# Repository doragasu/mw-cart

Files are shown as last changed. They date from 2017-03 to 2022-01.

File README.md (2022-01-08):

# WARNING: THIS PROJECT HAS MOVED

You can find the most recent version at the [mw-cart GitLab project page](https://gitlab.com/doragasu/mw-cart). This repository will be kept as is, and will not be updated anymore.

# mw-cart
MegaWiFi Cartridge

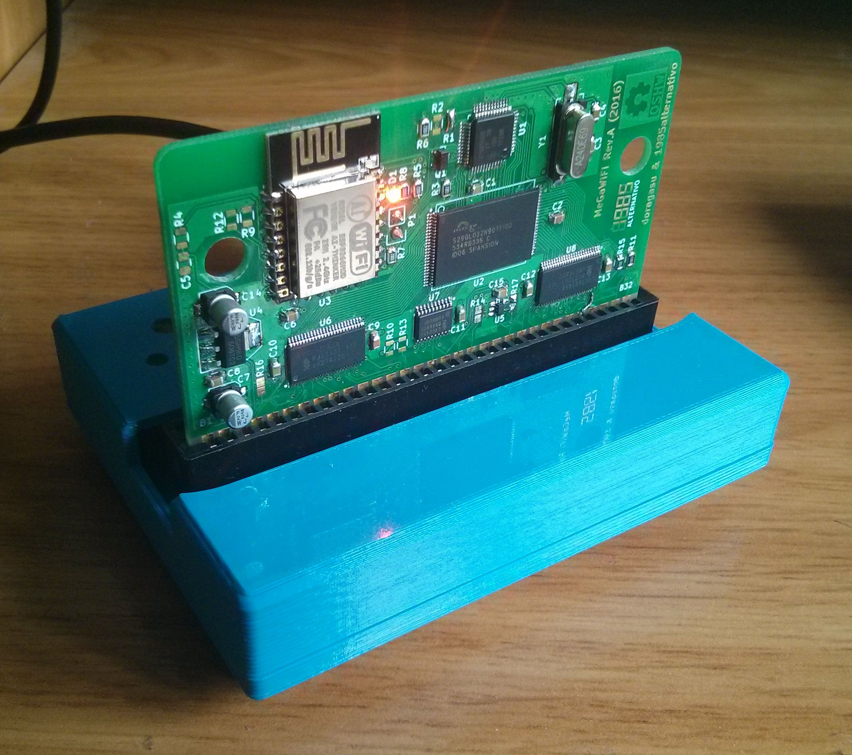
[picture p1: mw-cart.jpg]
mw-cart


This cartridge is for the MegaWiFi project. It consists of a cartridge for the SEGA Genesis/Megadrive console, along with a WiFi interface, allowing brave programmers to implement games with online gaming, leaderboards, evil DLCs, etc.

This project was initially created for 1985alternativo, but to this day, no brave soul has dared to make an online game using this cart. Will you give it a try?

Have a look to the [github project page](https://github.com/doragasu/mw) for more information.

## License
mw-cart is licensed under the [CERN OHL 1.2](http://www.ohwr.org/licenses/cern-ohl/v1.2) license. You are free to study, distribute and make modifications to the Documentation, under the aforementioned license terms. You are also free to make cartridges derived from the Documentation for non-commercial purposes. If you want to make a commercial Product using this Documentation, please contact me to obtain a licence.

## About CAD files
Electronic CAD design files are for KiCAD Open Source electronics design suite. Please install latest version along with KiCAD libraries to open the project. When opening schematic, KiCAD will most likely complain about missing library "doragasu". Despite this warning, the schematic should load nicely (using the cached libraries). To avoid this message, install [the missing library](https://github.com/doragasu/doragasu-kicad-lib) and make sure to configure it in the schematic editor.

The files under `gerber` directory are for PCB fabrication. Send them to your favorite PCB fab house.

Enjoy!

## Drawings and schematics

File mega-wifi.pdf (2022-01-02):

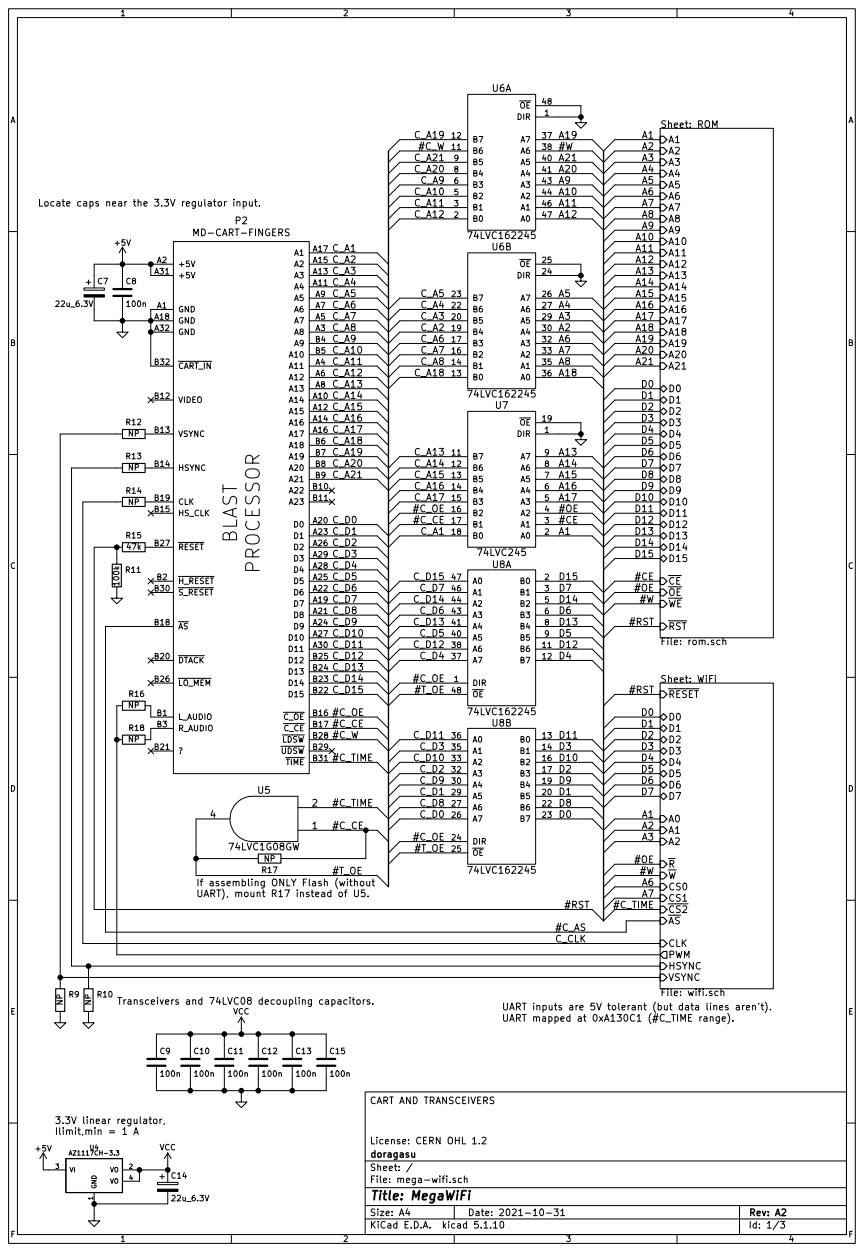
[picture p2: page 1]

Sheet: ROM
File: rom.sch A21 A20 A19 A18 A17 A16 A15 A14 A13 A12 A11 A10 A9A8A7A6A5A4A3A2A1D0 D1 D2 D3 D4 D5 D6 D7 D8 D9 D10 D11 D12 D13 D14 D15 RST

Locate caps near the 3.3V regulator input.

C_A6 | C_A4
C_A7 | C_A3
C_A8 | C_A2
C_A9 | C_A6

C_A11 | C_A8
C_A12 | C_A18

C_A21 | C_A15
C_D0 | C_A16

LO_MEM B26 RESET B27 | C_D6 | C_D7

C_D7 | C_D14
C_D8 | C_D6

If assembling ONLY Flash (without
UART), mount R17 instead of U5.

UART inputs are 5V tolerant (but data lines aren't).
UART mapped at 0xA130C1 (#C_TIME range).

License: CERN OHL 1.2 CART AND TRANSCEIVERS

File: mega-wifi.sch Sheet: / doragasu

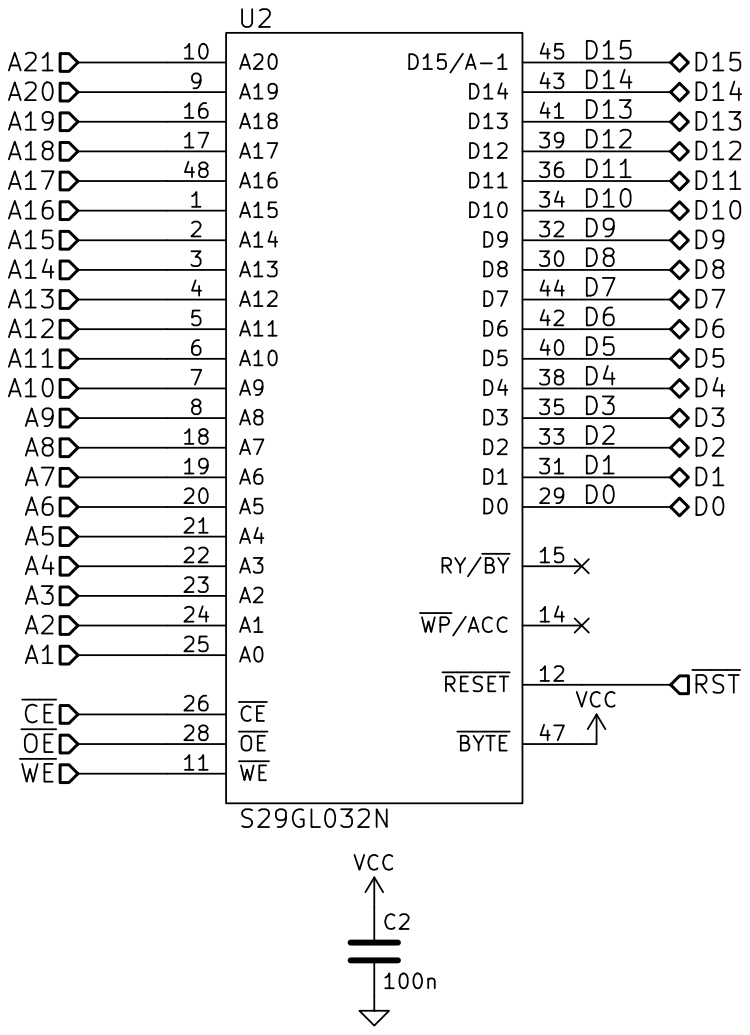
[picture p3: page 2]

License: CERN OHL 1.2 FLASH ROM

Id: 2/3 Title: MegaWiFi File: rom.sch Sheet: /ROM/ doragasu

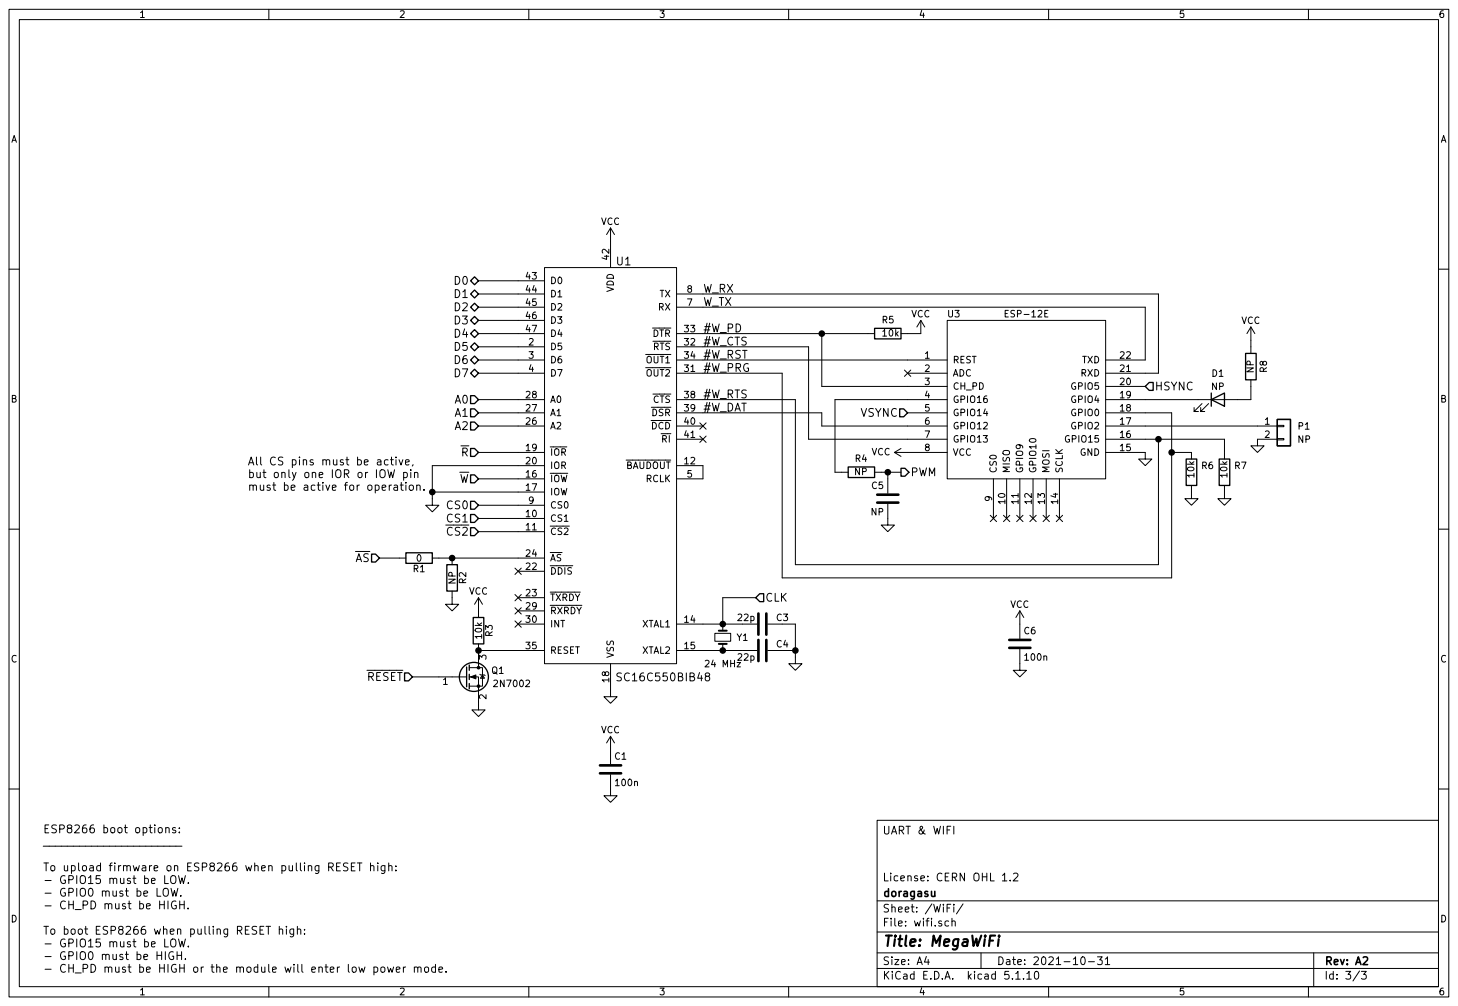
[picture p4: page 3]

IOR 19 D5 2 | #W_RTS

#W_RST
#W_PRG

All CS pins must be active,
but only one IOR or IOW pin
must be active for operation.

License: CERN OHL 1.2 UART & WIFI Y1

ESP8266 boot options: _______________________ To upload firmware on ESP8266 when pulling RESET high:

- GPIO15 must be LOW.
- GPIO0 must be LOW.
- CH_PD must be HIGH.
To boot ESP8266 when pulling RESET high:
- GPIO0 must be HIGH.
- CH_PD must be HIGH or the module will enter low power mode.

Id: 3/3 Title: MegaWiFi File: wifi.sch Sheet: /WiFi/ doragasu

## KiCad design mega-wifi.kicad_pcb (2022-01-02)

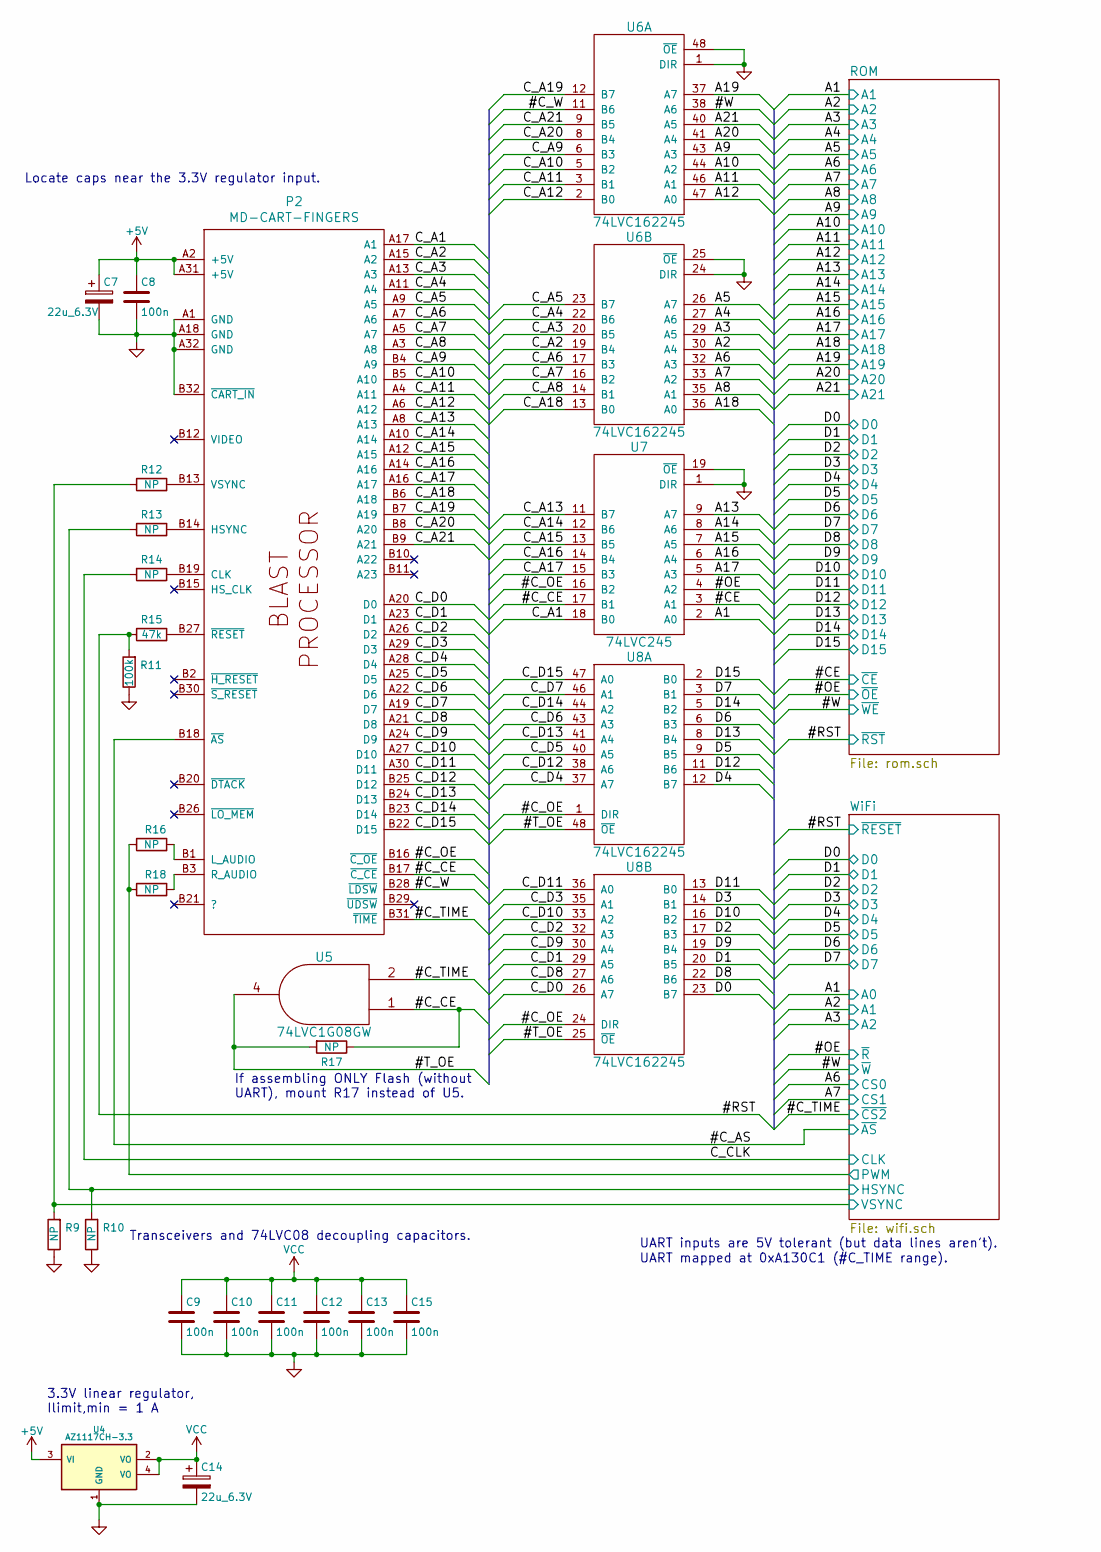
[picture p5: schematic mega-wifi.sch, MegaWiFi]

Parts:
C7, C14: 22u_6.3V; c_elec_4x4.5; LCSC# C250865
C8, C9, C10, C11, C12, C13, C15: 100n; C_0805; LCSC# C2830722
P2: MD-CART-FINGERS
R9, R10, R12, R13: NP; R_0805
R11: 100k; R_0805; LCSC# C237121
R14, R16, R17, R18: NP; JUMPER_0805
R15: 47k; R_0805; LCSC# C144558
U4: AZ1117CH-3.3; SOT-223; LCSC# C351784
U5: 74LVC1G08GW; SOT23-5; LCSC# C434068
U6, U8: 74LVC162245; TSSOP-48_6.1x12.5mm_Pitch0.5mm; LCSC# C6069
U7: 74LVC245; SSOP-20_4.4x6.5mm_Pitch0.65mm; LCSC# C393617

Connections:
+5V: C7.1, C8.1, P2.A2 (+5V), P2.A31 (+5V), U4.3 (VI)
/#CE: U7.3 (A1); also elsewhere on the board
/#C_AS: P2.B18 (~AS); also elsewhere on the board
/#C_CE: P2.B17 (~C_CE), R17.1, U5.1 (B), U7.17 (B1)
/#C_OE: P2.B16 (~C_OE), U7.16 (B2), U8.1 (DIR), U8.24 (DIR)
/#C_TIME: P2.B31 (~TIME), U5.2 (A); also elsewhere on the board
/#C_W: P2.B28 (~LDSW), U6.11 (B6)
/#OE: U7.4 (A2); also elsewhere on the board
/#RST: R11.2, R15.1; also elsewhere on the board
/#T_OE: R17.2, U5.4 (Y), U8.25 (~OE), U8.48 (~OE)
/#W: U6.38 (A6); also elsewhere on the board
/A1: U7.2 (A0); also elsewhere on the board
/A2: U6.30 (A4); also elsewhere on the board
/A3: U6.29 (A5); also elsewhere on the board
/A4: U6.27 (A6); also elsewhere on the board
/A5: U6.26 (A7); also elsewhere on the board
/A6: U6.32 (A3); also elsewhere on the board
/A7: U6.33 (A2); also elsewhere on the board
/A8: U6.35 (A1); also elsewhere on the board
/A9: U6.43 (A3); also elsewhere on the board
/A10: U6.44 (A2); also elsewhere on the board
/A11: U6.46 (A1); also elsewhere on the board
/A12: U6.47 (A0); also elsewhere on the board
/A13: U7.9 (A7); also elsewhere on the board
/A14: U7.8 (A6); also elsewhere on the board
/A15: U7.7 (A5); also elsewhere on the board
/A16: U7.6 (A4); also elsewhere on the board
/A17: U7.5 (A3); also elsewhere on the board
/A18: U6.36 (A0); also elsewhere on the board
/A19: U6.37 (A7); also elsewhere on the board
/A20: U6.41 (A4); also elsewhere on the board
/A21: U6.40 (A5); also elsewhere on the board
/C_A1: P2.A17 (A1), U7.18 (B0)
/C_A2: P2.A15 (A2), U6.19 (B4)
/C_A3: P2.A13 (A3), U6.20 (B5)
/C_A4: P2.A11 (A4), U6.22 (B6)
/C_A5: P2.A9 (A5), U6.23 (B7)
/C_A6: P2.A7 (A6), U6.17 (B3)
/C_A7: P2.A5 (A7), U6.16 (B2)
/C_A8: P2.A3 (A8), U6.14 (B1)
/C_A9: P2.B4 (A9), U6.6 (B3)
/C_A10: P2.B5 (A10), U6.5 (B2)
/C_A11: P2.A4 (A11), U6.3 (B1)
/C_A12: P2.A6 (A12), U6.2 (B0)
/C_A13: P2.A8 (A13), U7.11 (B7)
/C_A14: P2.A10 (A14), U7.12 (B6)
/C_A15: P2.A12 (A15), U7.13 (B5)
/C_A16: P2.A14 (A16), U7.14 (B4)
/C_A17: P2.A16 (A17), U7.15 (B3)
/C_A18: P2.B6 (A18), U6.13 (B0)
/C_A19: P2.B7 (A19), U6.12 (B7)
/C_A20: P2.B8 (A20), U6.8 (B4)
/C_A21: P2.B9 (A21), U6.9 (B5)
/C_CLK: R14.2; also elsewhere on the board
/C_D0: P2.A20 (D0), U8.26 (A7)
/C_D1: P2.A23 (D1), U8.29 (A5)
/C_D2: P2.A26 (D2), U8.32 (A3)
/C_D3: P2.A29 (D3), U8.35 (A1)
/C_D4: P2.A28 (D4), U8.37 (A7)
/C_D5: P2.A25 (D5), U8.40 (A5)
/C_D6: P2.A22 (D6), U8.43 (A3)
/C_D7: P2.A19 (D7), U8.46 (A1)
/C_D8: P2.A21 (D8), U8.27 (A6)
/C_D9: P2.A24 (D9), U8.30 (A4)
/C_D10: P2.A27 (D10), U8.33 (A2)
/C_D11: P2.A30 (D11), U8.36 (A0)
/C_D12: P2.B25 (D12), U8.38 (A6)
/C_D13: P2.B24 (D13), U8.41 (A4)
/C_D14: P2.B23 (D14), U8.44 (A2)
/C_D15: P2.B22 (D15), U8.47 (A0)
/D0: U8.23 (B7); also elsewhere on the board
/D1: U8.20 (B5); also elsewhere on the board
/D2: U8.17 (B3); also elsewhere on the board
/D3: U8.14 (B1); also elsewhere on the board
/D4: U8.12 (B7); also elsewhere on the board
/D5: U8.9 (B5); also elsewhere on the board
/D6: U8.6 (B3); also elsewhere on the board
/D7: U8.3 (B1); also elsewhere on the board
/D8: U8.22 (B6); also elsewhere on the board
/D9: U8.19 (B4); also elsewhere on the board
/D10: U8.16 (B2); also elsewhere on the board
/D11: U8.13 (B0); also elsewhere on the board
/D12: U8.11 (B6); also elsewhere on the board
/D13: U8.8 (B4); also elsewhere on the board
/D14: U8.5 (B2); also elsewhere on the board
/D15: U8.2 (B0); also elsewhere on the board
/WiFi/HSYNC: R10.2, R13.1; also elsewhere on the board
/WiFi/PWM: R16.1, R18.1; also elsewhere on the board
/WiFi/VSYNC: R9.2, R12.1; also elsewhere on the board
GND: C7.2, C8.2, C9.2, C10.2, C11.2, C12.2, C13.2, C14.2, C15.2, P2.A1 (GND), P2.A18 (GND), P2.A32 (GND), P2.B32 (~CART_IN), R9.1, R10.1, R11.1, U4.1 (GND), U5.3 (GND), U6.1 (DIR), U6.4 (GND), U6.10 (GND), U6.15 (GND), U6.21 (GND), U6.24 (DIR), U6.25 (~OE), U6.28 (GND), U6.34 (GND), U6.39 (GND), U6.45 (GND), U6.48 (~OE), U7.1 (DIR), U7.10 (GND), U7.19 (~OE), U8.4 (GND), U8.10 (GND), U8.15 (GND), U8.21 (GND), U8.28 (GND), U8.34 (GND), U8.39 (GND), U8.45 (GND); also elsewhere on the board
unnamed: P2.B1 (L_AUDIO), R16.2
unnamed: P2.B3 (R_AUDIO), R18.2
unnamed: P2.B13 (VSYNC), R12.2
unnamed: P2.B14 (HSYNC), R13.2
unnamed: P2.B19 (CLK), R14.1
unnamed: P2.B27 (~RESET), R15.2
VCC: C9.1, C10.1, C11.1, C12.1, C13.1, C14.1, C15.1, U4.2 (VO), U4.4 (VO), U5.5 (VCC), U6.7 (VCC), U6.18 (VCC), U6.31 (VCC), U6.42 (VCC), U7.20 (VCC), U8.7 (VCC), U8.18 (VCC), U8.31 (VCC), U8.42 (VCC); also elsewhere on the board

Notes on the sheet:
UART inputs are 5V tolerant (but data lines aren't).
3.3V linear regulator, Ilimit,min = 1 A
UART mapped at 0xA130C1 (#C_TIME range).
Locate caps near the 3.3V regulator input.
Transceivers and 74LVC08 decoupling capacitors.
If assembling ONLY Flash (without UART), mount R17 instead of U5.

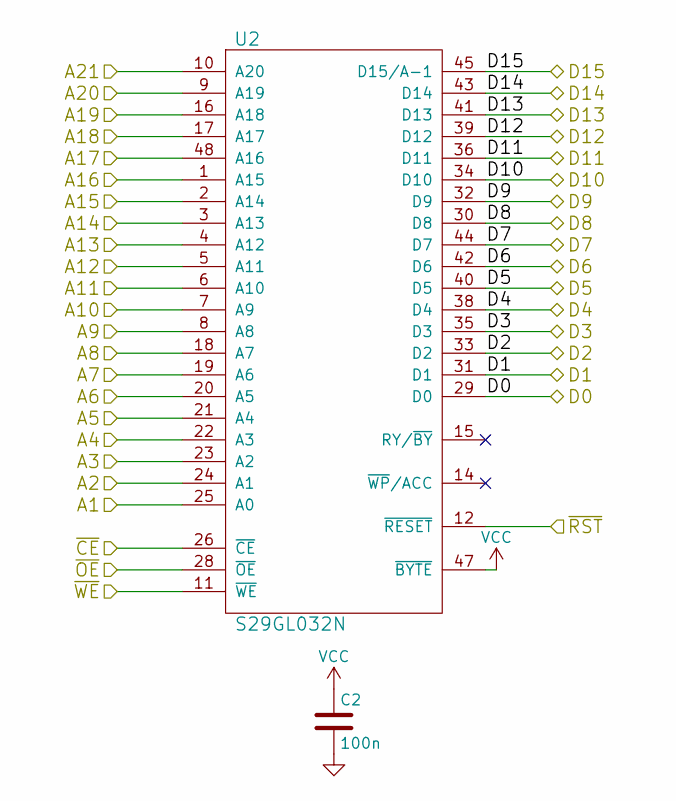
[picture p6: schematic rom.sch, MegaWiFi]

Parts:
C2: 100n; C_0805; LCSC# C2830722
U2: S29GL032N; TSOP48SP; LCSC# C62389

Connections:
/#CE: U2.26 (~CE); also elsewhere on the board
/#OE: U2.28 (~OE); also elsewhere on the board
/#RST: U2.12 (~RESET); also elsewhere on the board
/#W: U2.11 (~WE); also elsewhere on the board
/A1: U2.25 (A0); also elsewhere on the board
/A2: U2.24 (A1); also elsewhere on the board
/A3: U2.23 (A2); also elsewhere on the board
/A4: U2.22 (A3); also elsewhere on the board
/A5: U2.21 (A4); also elsewhere on the board
/A6: U2.20 (A5); also elsewhere on the board
/A7: U2.19 (A6); also elsewhere on the board
/A8: U2.18 (A7); also elsewhere on the board
/A9: U2.8 (A8); also elsewhere on the board
/A10: U2.7 (A9); also elsewhere on the board
/A11: U2.6 (A10); also elsewhere on the board
/A12: U2.5 (A11); also elsewhere on the board
/A13: U2.4 (A12); also elsewhere on the board
/A14: U2.3 (A13); also elsewhere on the board
/A15: U2.2 (A14); also elsewhere on the board
/A16: U2.1 (A15); also elsewhere on the board
/A17: U2.48 (A16); also elsewhere on the board
/A18: U2.17 (A17); also elsewhere on the board
/A19: U2.16 (A18); also elsewhere on the board
/A20: U2.9 (A19); also elsewhere on the board
/A21: U2.10 (A20); also elsewhere on the board
/D0: U2.29 (D0); also elsewhere on the board
/D1: U2.31 (D1); also elsewhere on the board
/D2: U2.33 (D2); also elsewhere on the board
/D3: U2.35 (D3); also elsewhere on the board
/D4: U2.38 (D4); also elsewhere on the board
/D5: U2.40 (D5); also elsewhere on the board
/D6: U2.42 (D6); also elsewhere on the board
/D7: U2.44 (D7); also elsewhere on the board
/D8: U2.30 (D8); also elsewhere on the board
/D9: U2.32 (D9); also elsewhere on the board
/D10: U2.34 (D10); also elsewhere on the board
/D11: U2.36 (D11); also elsewhere on the board
/D12: U2.39 (D12); also elsewhere on the board
/D13: U2.41 (D13); also elsewhere on the board
/D14: U2.43 (D14); also elsewhere on the board
/D15: U2.45 (D15/A-1); also elsewhere on the board
GND: C2.2, U2.27 (GND), U2.46 (GND); also elsewhere on the board
VCC: C2.1, U2.37 (VCC), U2.47 (~BYTE); also elsewhere on the board

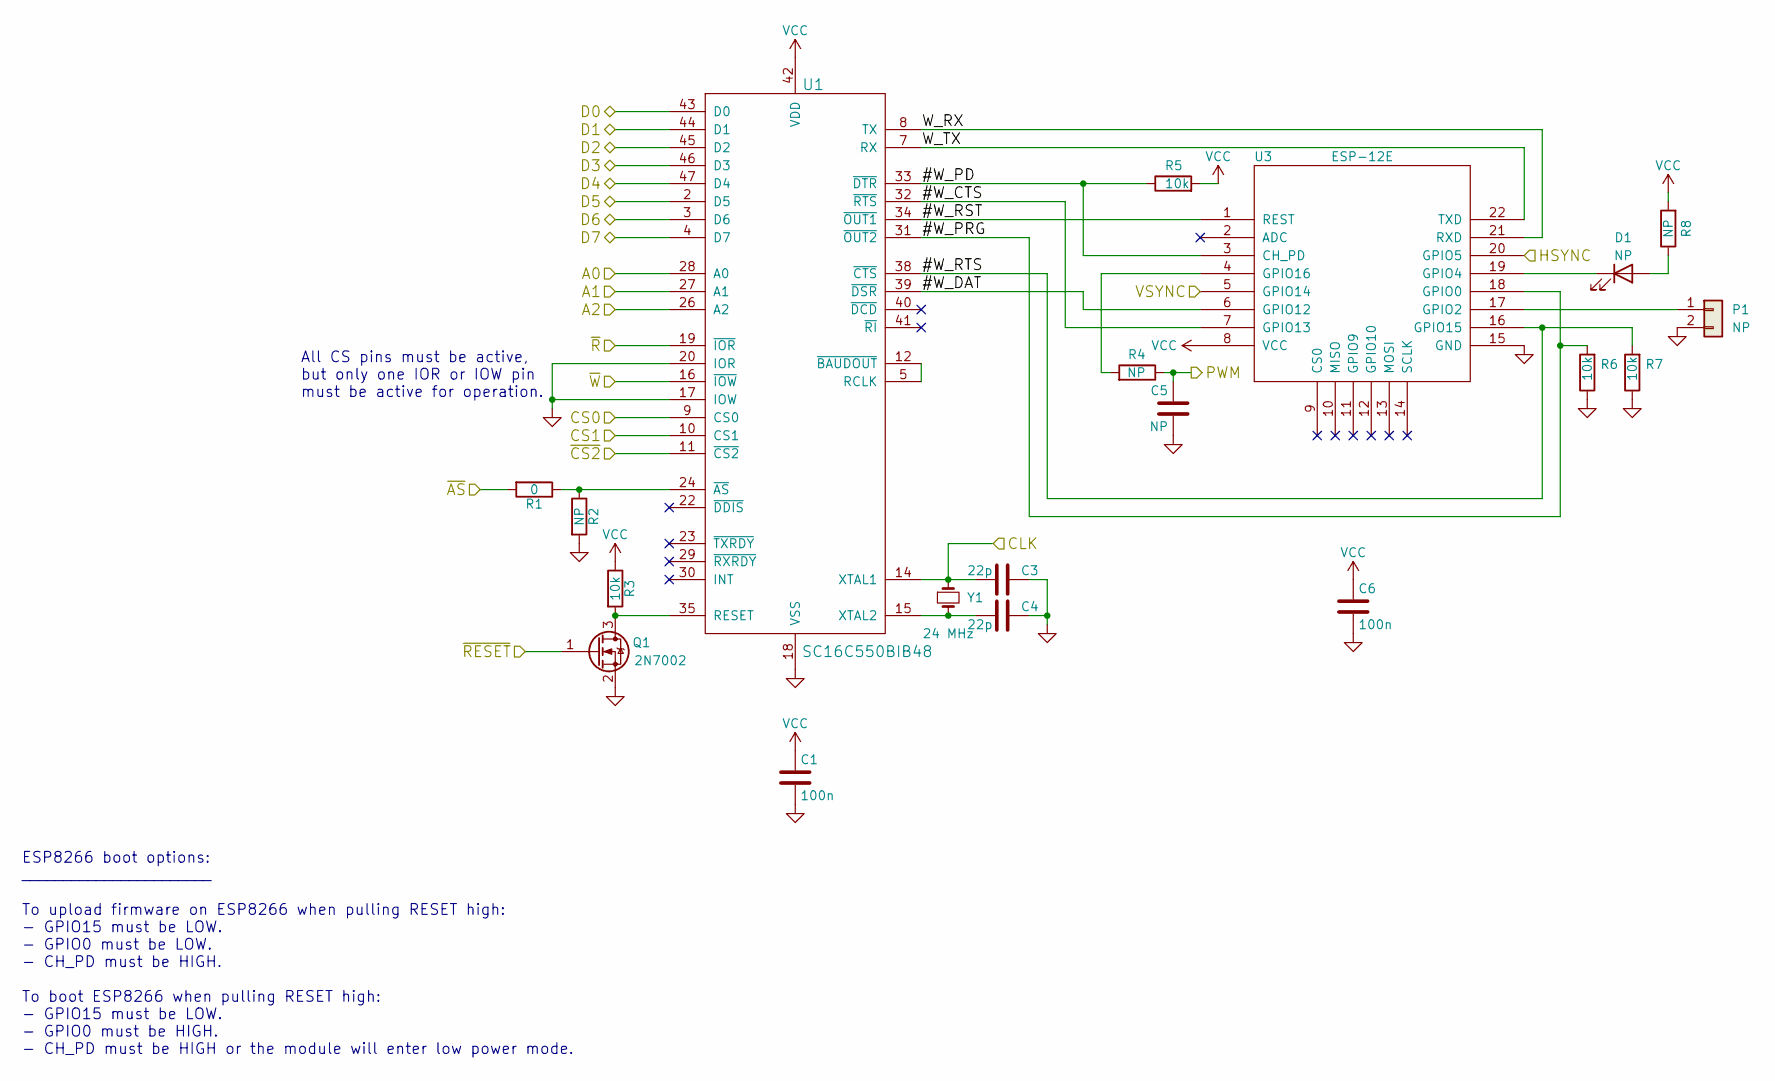
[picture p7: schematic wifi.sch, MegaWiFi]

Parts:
C1, C6: 100n; C_0805; LCSC# C2830722
C3, C4: 22p; C_0805; LCSC# C237185
C5: NP; C_0805; LCSC# C2830722
D1: NP; LED-0603
P1: NP; PinHeader_1x02_P2.54mm_Vertical
Q1: 2N7002; sot23; LCSC# C306856
R1: 0; JUMPER_0805; LCSC# C96345
R2, R4, R8: NP; R_0805
R3, R5, R6, R7: 10k; R_0805; LCSC# C2763777
U1: SC16C550BIB48; TQFP-48_7x7mm_Pitch0.5mm; LCSC# C84320
U3: ESP-12E; LCSC# C89297
Y1: 24 MHz; Crystal_HC49-SD_SMD; LCSC# C259050

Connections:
/#C_AS: R1.2; also elsewhere on the board
/#C_TIME: U1.11 (~CS2); also elsewhere on the board
/#OE: U1.19 (~IOR); also elsewhere on the board
/#RST: Q1.1 (G); also elsewhere on the board
/#W: U1.16 (~IOW); also elsewhere on the board
/A1: U1.28 (A0); also elsewhere on the board
/A2: U1.27 (A1); also elsewhere on the board
/A3: U1.26 (A2); also elsewhere on the board
/A6: U1.9 (CS0); also elsewhere on the board
/A7: U1.10 (CS1); also elsewhere on the board
/C_CLK: C3.2, U1.14 (XTAL1), Y1.1; also elsewhere on the board
/D0: U1.43 (D0); also elsewhere on the board
/D1: U1.44 (D1); also elsewhere on the board
/D2: U1.45 (D2); also elsewhere on the board
/D3: U1.46 (D3); also elsewhere on the board
/D4: U1.47 (D4); also elsewhere on the board
/D5: U1.2 (D5); also elsewhere on the board
/D6: U1.3 (D6); also elsewhere on the board
/D7: U1.4 (D7); also elsewhere on the board
/WiFi/#W_CTS: U1.32 (~RTS), U3.7 (GPIO13)
/WiFi/#W_DAT: U1.39 (~DSR), U3.6 (GPIO12)
/WiFi/#W_PD: R5.1, U1.33 (~DTR), U3.3 (CH_PD)
/WiFi/#W_PRG: R6.2, U1.31 (~OUT2), U3.18 (GPIO0)
/WiFi/#W_RST: U1.34 (~OUT1), U3.1 (REST)
/WiFi/#W_RTS: R7.2, U1.38 (~CTS), U3.16 (GPIO15)
/WiFi/HSYNC: U3.20 (GPIO5); also elsewhere on the board
/WiFi/PWM: C5.1, R4.1; also elsewhere on the board
/WiFi/VSYNC: U3.5 (GPIO14); also elsewhere on the board
/WiFi/W_RX: U1.8 (TX), U3.21 (RXD)
/WiFi/W_TX: U1.7 (RX), U3.22 (TXD)
GND: C1.2, C3.1, C4.1, C5.2, C6.2, P1.2, Q1.2 (S), R2.2, R6.1, R7.1, U1.17 (IOW), U1.18 (VSS), U1.20 (IOR), U3.15 (GND); also elsewhere on the board
unnamed: C4.2, U1.15 (XTAL2), Y1.2
unnamed: D1.1 (K), U3.19 (GPIO4)
unnamed: D1.2 (A), R8.1
unnamed: P1.1, U3.17 (GPIO2)
unnamed: Q1.3 (D), R3.2, U1.35 (RESET)
unnamed: R1.1, R2.1, U1.24 (~AS)
unnamed: R4.2, U3.4 (GPIO16)
unnamed: U1.5 (RCLK), U1.12 (~BAUDOUT)
VCC: C1.1, C6.1, R3.1, R5.2, R8.2, U1.42 (VDD), U3.8 (VCC); also elsewhere on the board

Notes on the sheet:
ESP8266 boot options: _______________________ To upload firmware on ESP8266 when pulling RESET high: - GPIO15 must be LOW. - GPIO0 must be LOW. - CH_PD must be HIGH. To boot ESP8266 when pulling RESET high: - GPIO15 must be LOW. - GPIO0 must be HIGH. - CH_PD must be HIGH or the module will enter lo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
All CS pins must be active, but only one IOR or IOW pin must be active for operation.

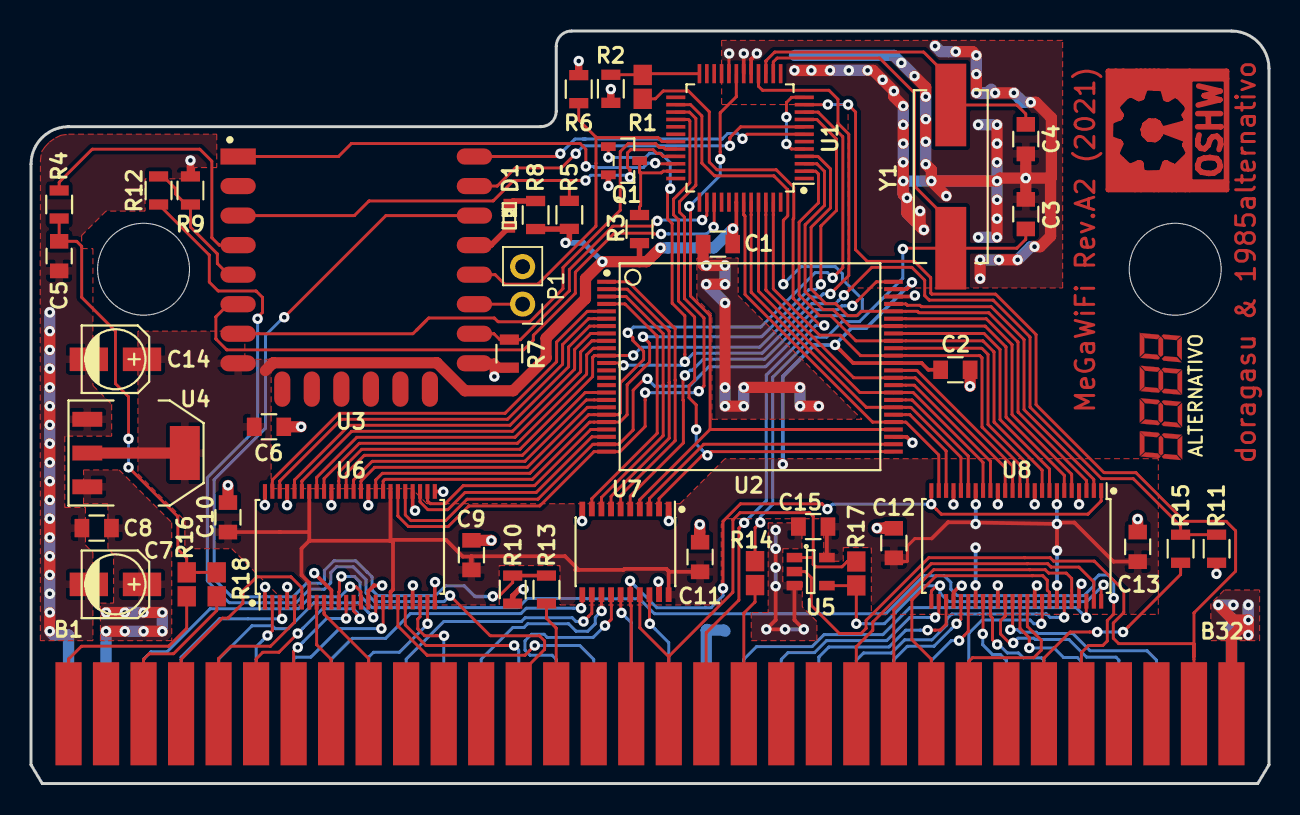
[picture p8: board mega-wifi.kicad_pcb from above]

Board: 2 copper layers, 83.8 x 51.0 mm, 47 parts (0 on the bottom side), 113 nets.

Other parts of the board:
Symbol_OSHW-Logo_CopperTop_Negative: VAL**; Symbol_OSHW-Logo_CopperTop_Negative

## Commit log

2017-03-24 Added design files.
    [mega-wifi-B.Cu.gbr, mega-wifi-B.Mask.gbr, mega-wifi-Edge.Cuts.gbr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]
2018-04-07 Updated to latest KiCad and libraries version.
    [mega-wifi.kicad_pcb, mega-wifi.sch, rom.sch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]
2021-10-30 Update schematic components to latest library
    [mega-wifi.sch, rom.sch, wifi.sch]
2021-10-30 Update 3D models to latest library
    [mega-wifi.kicad_pcb]
2022-01-02 Update to Rev.A2
    [mega-wifi-B.Cu.gbr, mega-wifi-B_Cu.gbr, mega-wifi-B_Mask.gbr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]

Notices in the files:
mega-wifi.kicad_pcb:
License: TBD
